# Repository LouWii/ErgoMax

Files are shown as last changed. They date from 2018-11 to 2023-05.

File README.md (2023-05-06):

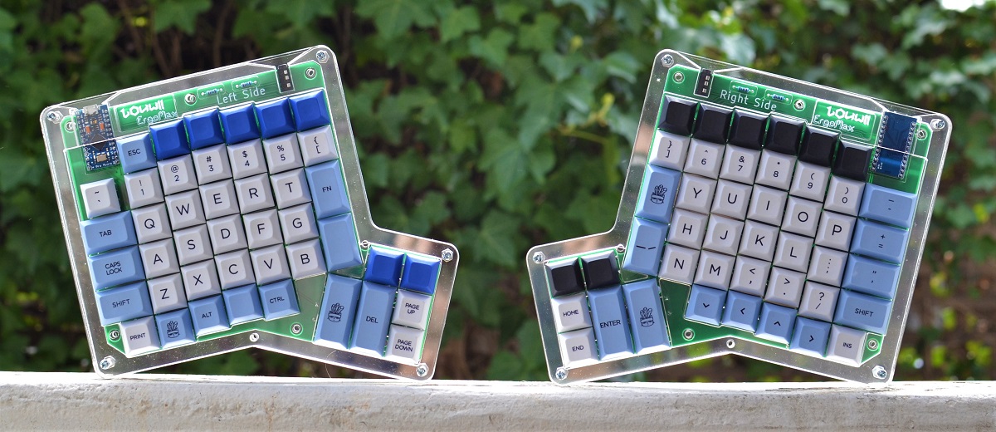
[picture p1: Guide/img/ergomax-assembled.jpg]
Ergomax Keyboard


# ErgoMax

The ErgoMax is a split ergonomic keyboard.

It is based on the ErgoDox, a popular split ergonomic keyboard ([learn more](https://www.ergodox.io/)). 

Its main features/differences are:

* extra top row for F1-F12 keys
* hot-swappable switches
* uses 2 ProMicro controllers (one for each side)
* QMK firmware
* 2 versions of the PCBs:
    * a reversible left+right combined
    * 2 separate PCBs, one for each side
* either side can be master/slave
* both sides can be master (both sides need to be connected via USB in that case), allow for a 1 side only setup
* 2 input pins left (perfect for a rotary encoder!)
* **DIY friendly**: it's really super easy to assemble yourself. The hardest part is probably the ProMicro. But it's still very accessible for beginners.
* multi layer acrylic case

## Layout

While a lot of mechanical keyboard users seem to prefer simplistic, minimal keyboards, the ErgoMax goes the opposite way.

The layout is the same as the ErgoDox, **with an extra top row** for *F1* to *F12* keys, adding more room for activities.

Here's an example:

ergomax-default -layout

## Hotswap - change switches whenever you want

The keyboard PCB has been designed to use **Kailh MX hotswap sockets**. You won't be able to solder the switches directly on the PCBs, you **must** use Kaihl MX sockets.

Switches will plug into the sockets, meaning no solder required for them, and most importantly, meaning that you can remove them and change them easily (hence the *hotswap*...).

## Controller

Each side of the keyboard is controlled via a ProMicro, which is a cheap, small Arduino compatible board running on an ATmega32u4.

The 2 sides can be connected via a 3.5mm jack, just like the original ErgoDox. However, as the 2 sides possess their own ProMicro, that means they can also be working totally independently if needed.

There are 2 pins free on each of the ProMicros, which can be used for whatever you want. I believe it would be possible to drive a RGB strip from it, since it requires only 1 drive pin (you would need to get GND and +5V from somewhere on the PCB). I was able to use both pins to add a rotary encoder.

### Jack connector

I tried to use the same 3.5mm TRRS jack socket as the original ErgoDox, which is a *CP-43514*. But it's not super common, so I changed it for a *PJ320A* (same as *MJ-4PP-9*).

### Firmware

Check the [guides](Guide/README.md)

## Third Party Libraries

We are using several libraries in this project.

* keyboard_parts.pretty [https://github.com/colemarkham/keyboard_parts.pretty](https://github.com/colemarkham/keyboard_parts.pretty) - The Kailh hotswap socket footprint is taken from this project, and has been slightly modified. The 2U stabilizer footprint is from this library as well.
* ProMicroKiCad [https://github.com/Biacco42/ProMicroKiCad](https://github.com/Biacco42/ProMicroKiCad) - The schema and footprint for the ProMicro
* Keebio-Parts.pretty [https://github.com/keebio/Keebio-Parts.pretty](https://github.com/keebio/Keebio-Parts.pretty) - Footprints for the diodes, the PJ320A jack connector, and resistors

### 3D models

Kicad can generate nice 3D previews of PCBs and their components.

As we're using components that are not included in KiCad 3d templates, you'll need to add the next models into your KiCad template folder. On Windows, it's `C:\Users\YOURNAME\kicad\template`, on OSX it's `/Users/YOURNAME/kicad/template`. If the folder doesn't exist, create it.

The 3D models of the hotswap sockets can be found there: [https://github.com/qmk/qmk_hardware](https://github.com/qmk/qmk_hardware). Copy `kailh_socket_mx.stp` into your KiCad template folder.

I couldn't find a 3D model for the PJ320A jack connector. The closest I found is this [https://www.cui.com/product/resource/3dmodel/sj2-3574a-smt-tr](https://www.cui.com/product/resource/3dmodel/sj2-3574a-smt-tr), which gives a good preview of a real PJ320A. Copy `CUI_SJ2-3574A-SMT-TR.step` into your KiCad template folder.

I modified this MX Switch 3D model [https://grabcad.com/library/cherry-mx-switches-mx-1](https://grabcad.com/library/cherry-mx-switches-mx-1) and included it in the `libs/3dmodels` folder of the project as `MX-clean-ergomax.step`. 

I also modified a 2U stabilizer model that I found there [https://grabcad.com/library/cherry-mx-stabilizer-mx-1](https://grabcad.com/library/cherry-mx-stabilizer-mx-1). The file is also included in the `libs/3dmodels` folder of the project as `Stabilizer-closed-ergomax.step`.

I once again modified a ProMicro 3D model [https://grabcad.com/library/arduino-pro-micro-1](https://grabcad.com/library/arduino-pro-micro-1). The file is called `Pro-micro-clean-ergomax.step` and is stored in `libs/3dmodels`.

## Print the PCBs

Here are some manufacturers that can print PCBs for you. They are not in any particular order and I don't have any partnership of any sort either.

* [https://pcbshopper.com/ - price comparison](https://pcbshopper.com/) 
* [https://jlcpcb.com/](https://jlcpcb.com/)
* [https://www.pcbway.com/](https://www.pcbway.com/)
* [https://oshpark.com/](https://oshpark.com/)
* [https://www.pcbcart.com/](https://www.pcbcart.com/)
* [https://www.7pcb.ca/](https://www.7pcb.ca/pcb-fabrication/)
* [https://www.4pcb.com/](https://www.4pcb.com/)
* [https://www.pcbgogo.com/](https://www.pcbgogo.com/)
* [https://dirtypcbs.com/](https://dirtypcbs.com/)

## Assembly

Check the [guides](Guide/README.md)

## Case

[See Case readme](./Case/)

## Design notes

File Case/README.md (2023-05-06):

## Case

### Acrylic

A case composed of different laser-cut acrylic layers.

[More](./Acrylic/)

### Solid bottom

A solid 3d bottom case, potentially usable for 3d printing or CNC machining.

[More](./Solid%20Bottom%20Case/)

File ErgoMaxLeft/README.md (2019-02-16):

# ErgoMax - Left side

This is the left side, for the left hand.

## PCB

Render from Kicad (light source in Kicad isn't changeable...)

ergomax-left-pcb-4-front

ergomax-left-pcb-4-back

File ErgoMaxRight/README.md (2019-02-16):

# ErgoMax - Right side

This is the right side, for the right hand.

## PCB

Render from Kicad (light source in Kicad isn't changeable...)

ergomax-right-pcb-4-front

ergomax-right-pcb-4-back

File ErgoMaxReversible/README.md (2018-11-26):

# ErgoMax Reversible

As its name suggests, the reversible PCB can be used for either the left side or right side. 

## PCB

Render from KiCad.

ergomax-reversible-rightside

ergomax-reversible-leftside

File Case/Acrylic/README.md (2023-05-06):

## Case - Acrylic

A case composed of different laser-cut acrylic layers.

The design is dependant on using different thicknesses for the layers. The thickness availability depends on where you get the acrylic laser cut, hence why the designs might need to be adjusted if you can't source the correct thickness.

### MakerLabs

[More](./MakersLabs/)

### Ponoko

[More](./Ponoko/)

### Work files

[More](./WIP/)

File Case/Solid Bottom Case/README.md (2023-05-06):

## Case - Solid Bottom

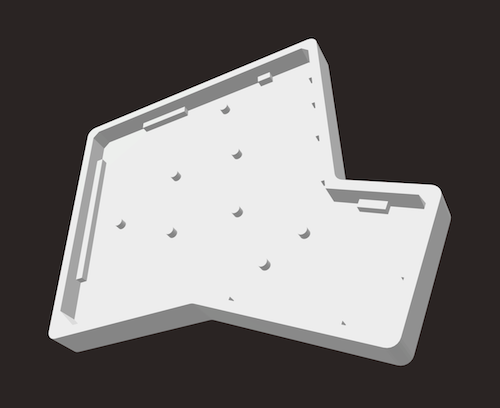
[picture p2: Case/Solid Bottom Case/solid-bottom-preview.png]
Ergomax bottom case 3d preview


A solid bottom case, potentially usable for 3d printing or CNC machining.

I never went further with the idea. I can't say for sure if the 3d models are good for any usage.

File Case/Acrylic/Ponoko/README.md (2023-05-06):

## Acrylic Case - Ponoko

This was an attempt at producing the files to get them laser cut with Ponoko.

I never pursued that idea, I can't confirm those files work. Technically, they should.

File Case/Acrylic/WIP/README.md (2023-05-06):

## Acrylic Case - Work files

The files in this folder were used during the designing process of the acrylic case.

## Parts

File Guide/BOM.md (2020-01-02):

# BOM (list of components)

This is for **one side**. If you're making 2 sides, double that up.

* 1x ProMicro board (and 2 2.52mm pin headers)
* 2x 2.2kohm resistors
* 1x PJ-320A or MJ-4PP-9 3.5mm jack connector
* 44x Kailh MX sockets
* 44x 1N4148 diodes (**through hole**)
* 44x MX Cherry (or MX compatible) keyboard switches
* 2x 2U stabilizers (optional)

### About diodes

Given the important number of diodes types/models out there, I made some research on what's a good diode/bad diode for a keyboard, because I had no idea (yay, learning!). Turns out it's not that easy to understand without a good knowledge in electronics. But at the same time, keyboards don't require a really specific diode, just one that has a switching time that's short enough(?). So in the end, the easiest solution is to use a 1N4148, which is one of the most common diodes, is cheap, and apparently is a good fit for a keyboard.

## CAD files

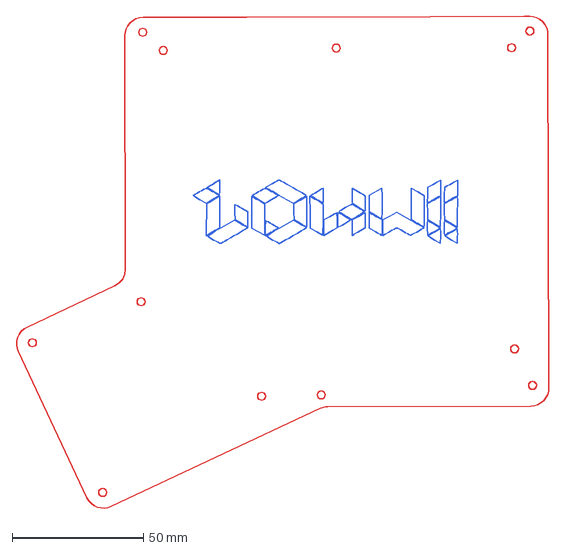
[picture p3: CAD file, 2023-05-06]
Case/Acrylic/MakersLabs/Layer 5 - right.dxf
202.9 x 188.2 mm

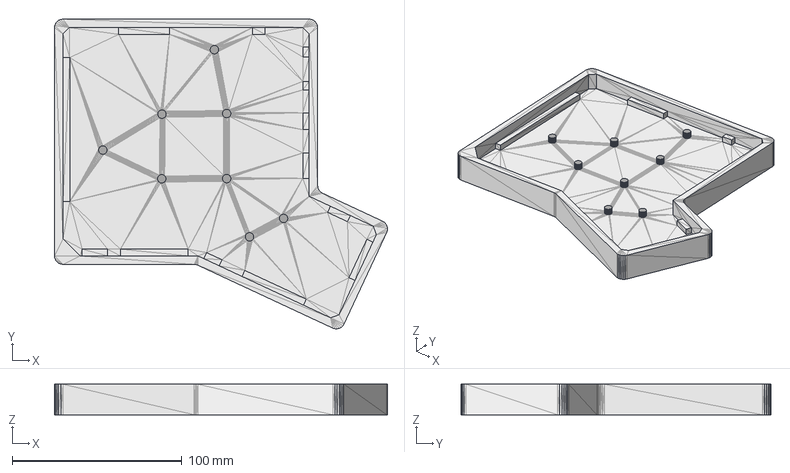
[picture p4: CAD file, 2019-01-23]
Case/Solid Bottom Case/ErgoMax-Left-Case.step
196.5 x 182.8 x 18.0 mm

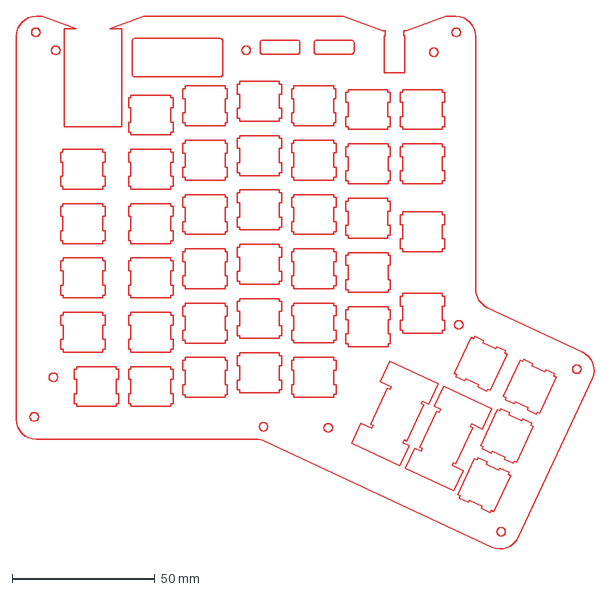
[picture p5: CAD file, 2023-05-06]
Case/Acrylic/MakersLabs/Layer 3.dxf
202.8 x 187.7 mm

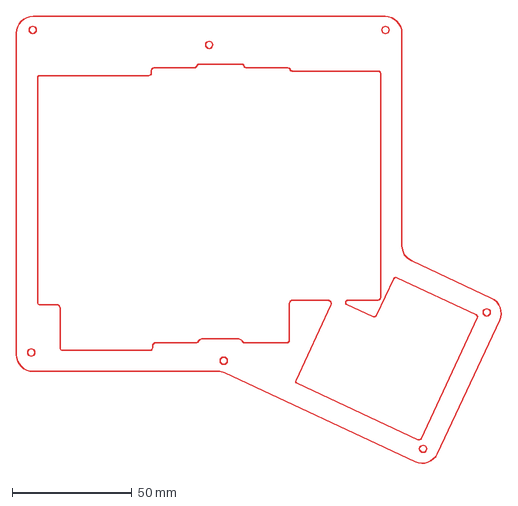
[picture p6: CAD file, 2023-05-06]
Case/Acrylic/MakersLabs/Layer 1.dxf
202.8 x 187.7 mm

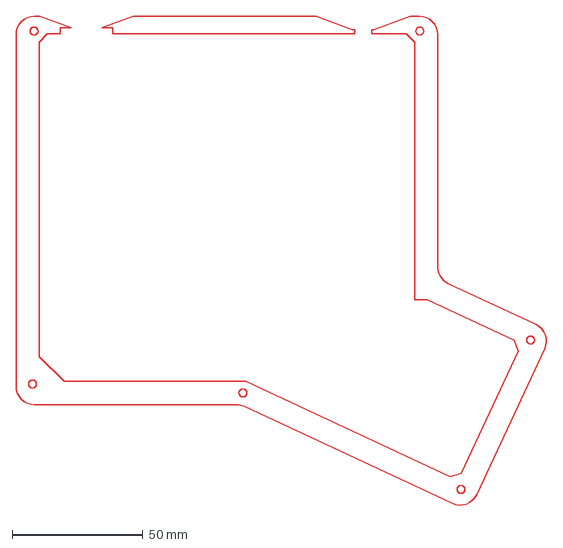
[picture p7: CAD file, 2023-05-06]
Case/Acrylic/MakersLabs/Layer 4.dxf
202.8 x 187.7 mm

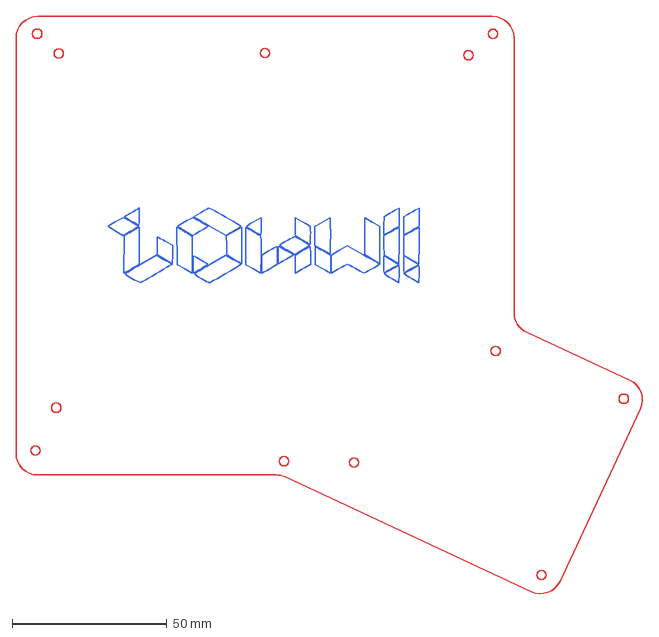
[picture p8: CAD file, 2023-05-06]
Case/Acrylic/MakersLabs/Layer 5 - left.dxf
202.8 x 187.7 mm

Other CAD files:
CAD/Acrylic/left - plate.dwg
Case/Acrylic/Ponoko/ponoko - layer 1 3 5.dwg
Case/Acrylic/WIP/Layer all.dwg
Case/left - PCB silk.dwg
Case/Acrylic/Ponoko/ponoko - layer 2 no extra.dwg
Case/Acrylic/WIP/left - layer 3 - plate.dwg
Case/Solid Bottom Case/ErgoMax-Left.stl
Case/Acrylic/Ponoko/ponoko - layer 2 doubled no extra.dwg
Case/Acrylic/WIP/left - layer 1.dwg
Case/Acrylic/Ponoko/ponoko - layer 4 with extra.dwg
Case/Acrylic/WIP/left - bottom.dwg
Case/Acrylic/Ponoko/ponoko - layer 1 3 5 no extra.dwg
Case/Acrylic/MakersLabs/Layer 2.dxf
Case/Acrylic/Ponoko/ponoko - layer 4 doubled no extra.dwg
Case/Acrylic/Ponoko/ponoko - layer 4 no extra.dwg
Case/Acrylic/WIP/left - layer 2.dwg
Case/Acrylic/WIP/left - layer 4.dwg
Case/Solid Bottom Case/ErgoMax-Left.dwg

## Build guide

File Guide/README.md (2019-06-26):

# Guides

* [Assembly](ASSEMBLY.md)
* [Firmware](FIRMWARE.md)

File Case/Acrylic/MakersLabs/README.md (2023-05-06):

## Acrylic Case - MakerLabs

Ergomax acrylic case laser cut

This is the version of the case that I got laser cut at a local shop called MakerLabs. It's the only one I have, and used for a while on my ErgoMax. It's using different thicknesses of acrylic sheets.

* Layer 1: 3mm (top)
* Layer 2: 4.5mm
* Layer 3: 3mm
* Layer 4: 6mm
* Layer 5: 3mm (bottom)

Each file works for any side, except the layer 5 that has a logo on it which is why there's a separate left and right.

The idea was to get the logo etched on the bottom layer, but it apaprently had issues and I was not able to get that done.

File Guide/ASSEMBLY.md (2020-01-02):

# Assembly

Here comes the fun part!

## Parts list

Make sure you have everything, check the [BOM](BOM.md)

## Process

First, make sure you understand on which side of the PCB you're supposed to solder/place the component on. This is easy for the left/right PCBs, a bit harder for the reversible PCB version.

The top of the PCB is where the switches will be on. On that side, we'll also have the ProMicro, 3.5mm jack connector, the 2 resistors and the 2 stabilizers.

On the bottom of the PCB, we'll have the 44 Kailh sockets and the 44 diodes.

**Note:** The 2 resistors can probably be soldered on the back, if you want to.

To give you an idea, here are the assembled PCBs.

### Left Side

#### Front

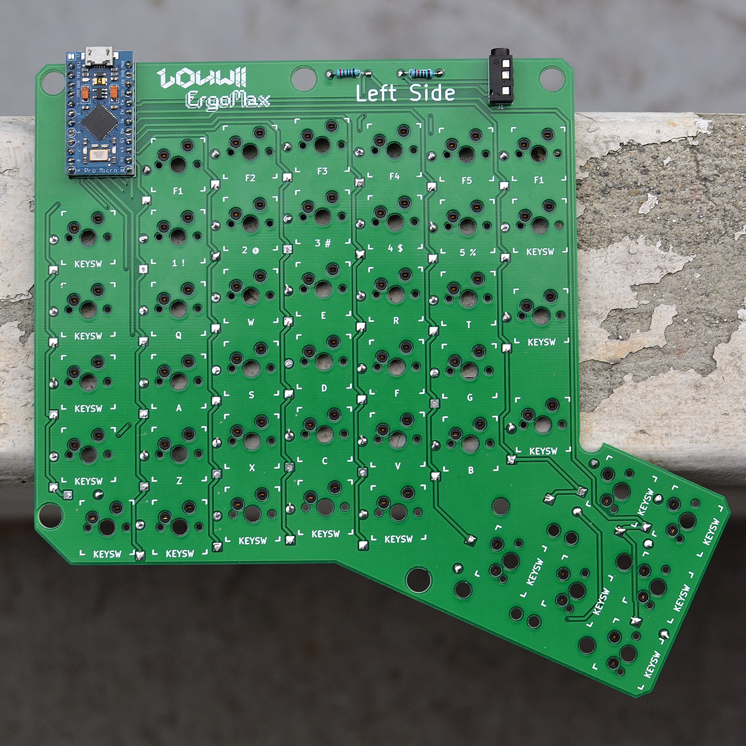
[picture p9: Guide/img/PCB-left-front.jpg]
Left PCB - front


#### Back

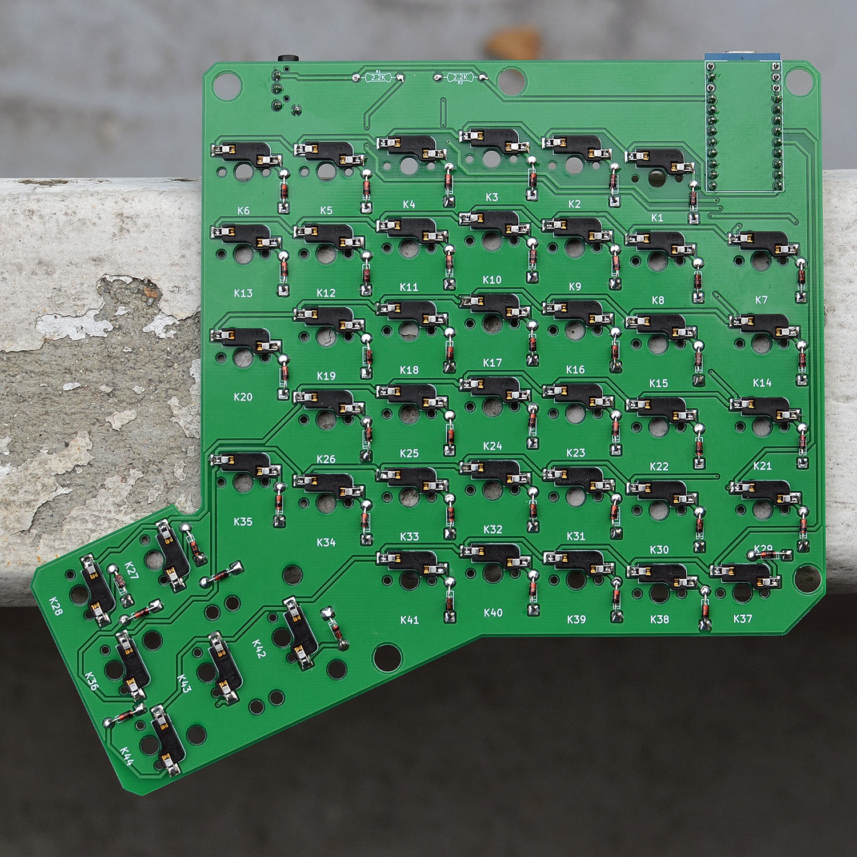
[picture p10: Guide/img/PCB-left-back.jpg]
Left PCB - back


### Right Side

#### Front

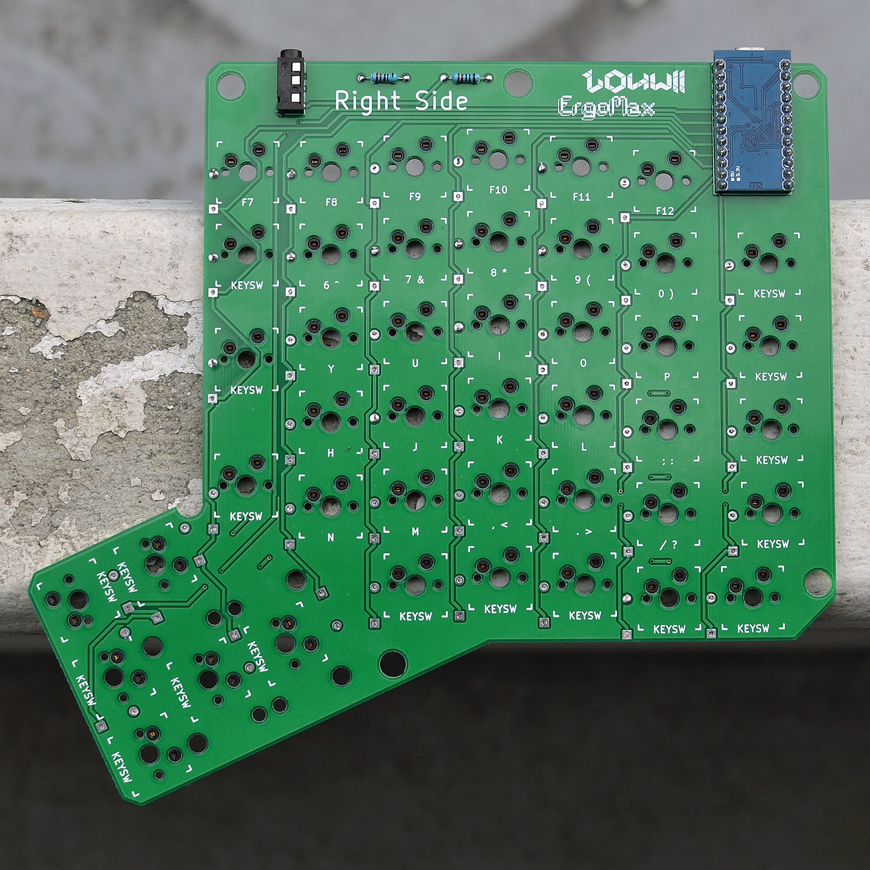
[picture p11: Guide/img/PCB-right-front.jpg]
Right PCB - front


#### Back

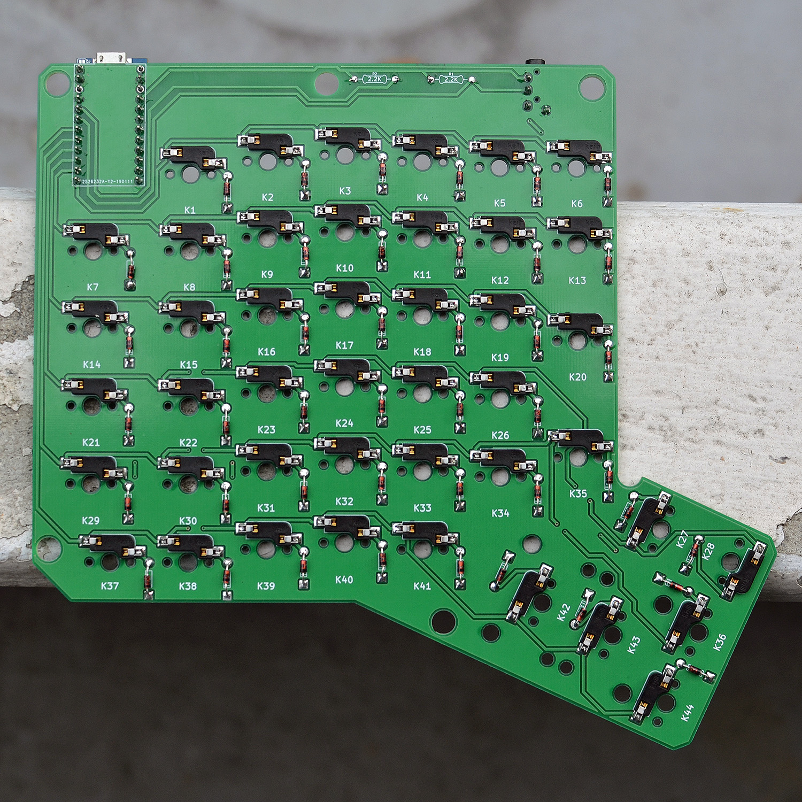
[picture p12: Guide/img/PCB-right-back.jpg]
Right PCB - back


### Step by step

#### Inserting Kailh sockets

The sockets fit very tightly on the PCB, maybe a bit too tight as they can be hard to put them in place. The good news is: this will prevent them from getting pulled off of the PCB when inserting a switch.

I recommend using a flat piece of wood to evenly put pressure on the socket until it sits flush with the PCB. You might need to put some good force on it. Make sure the socket is really flush with the PCB, otherwise it'll be harder to solder the socket later on.

I know, this isn't really fun. But take your time, don't rush, you might end up with a broken socket or worse.

#### Soldering the diodes

#### Soldering the resistors

#### Soldering the jack connector

#### Testing the ProMicro

Before soldering the ProMicro on the PCB, I advise you to test it. If, for some reason, the ProMicro doesn't work, it'll be a pain to remove.

Get a micro-USB cable, and flash a firmware on it.

#### Soldering the ProMicro

We're almost there! The hardest part left, the ProMicro.

The goal is not to mess it up and not bridge 2 pins. Take your time, do this in a well lit place (use your phone as a flashlight if needed). The pins and holes/pads are small and don't require a lot of solder. Heat up the pad an pin and place a small amount of solder. If you're having issues, a bit of flux might help.

Once done, make sure your solders are clean and that there are no bridges at all (2 pins or pads touching because you put too much solder on).

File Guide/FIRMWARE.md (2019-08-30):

# Firmware

Ergomax's firmware is based on [QMK](https://qmk.fm/), the (most?) popular firmware for custom keyboards.

The firmware is hosted on a separate repository (fork of QMK) in the *ergomax-keyboard* branch: [LouWii/qmk_firmware](https://github.com/LouWii/qmk_firmware)

To read more, go to the Ergomax folder [qmk/keyboards/ergomax](https://github.com/LouWii/qmk_firmware/tree/ergomax-keyboard/keyboards/ergomax)

### Keyboard Firmware Builder

[kbfirmware.com](https://kbfirmware.com/) is a nice tool that makes it easy to create a firmware based on QMK. You just have to setup your layout, enter the settings, enter the layout and layers, enter macros and even custom code, and then the tool compiles a firmware for you, or you can even download the source files if you want to.

I've created a file for the left side and right side so you don't have to setup everything in the tool. Just upload `ErgoMaxLeft/kfb-layout.json` or  `ErgoMaxRight/kfb-layout.json` and add your own customizations.

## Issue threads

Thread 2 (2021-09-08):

Case Information

leifniem, 2021-09-08:
A friend of mine wants my help building this board and i'm a little lost on the case part of the keyboard.

The included STEP / STL file would be suitable for 3D printing if i'm not mistaken, but it seems to be lacking the cutouts for the connectors, if i assume correctly.

On the acrlyic version i fail to understand if multiple middle layers are needed to acommodate the distance between switches and PCB, or alternatively a thicker middle part.

Sorry to bug if those are things that should be self-explanatory.

Thanks :)

LouWii, 2021-09-18:
Hi,

I'll be completely honest, I'm a complete noob in regards to 3d modelling. And I don't remember entirely what I produced for this board. The step/stl is probably un-complete, since I didn't go for 3d printing. I used it more as a preview to see how it would look.

The acrylic version should work though, since that's the route I went for. But again, I don't remember entirely what I did there 🤦‍♂️ The workshop I went to didn't have a large choice of thicknesses, so I had to accommodate for that in my design.

leifniem, 2021-09-18:
No worries, my friend just ordered all the parts so it's not remotely too late :)

But good to know my assumption about the 3D thing was right. With the vector files of the acrylic I should be able to whip up a printable case I think, I'll let you know in case we try that.

Thanks a lot and I hope you had a great vacation :)

LouWii, 2021-09-18:
Good luck! I'd love to see a few pics once it's all built

leifniem, 2022-02-17:
> Do you know how thick the acrylic needs to be to cut it?

We went for a 3D printed case, so I sadly do not

jaspreetlall, 2023-05-02:
@leifniem Any chance you could share the 3D printable case files? Would really appreciate if you could.

Thank you.

leifniem, 2023-05-02:
> @leifniem Any chance you could share the 3D printable case files? Would really appreciate if you could.
>
> Thank you.

Never got around to fixing them. How fit are you with CAD?

jaspreetlall, 2023-05-02:
No worries. I thought of asking since you mentioned choosing to go with printing. Thank you for your reply though.

And I barely ever used CAD but have someone I know who can tinker a little bit. They'd be able to tweak things but not design per se. What kind of fixes might be needed? I can definitely ask them.

leifniem, 2023-05-02:
> No worries. I thought of asking since you mentioned choosing to go with printing. Thank you for your reply though.
>
> And I barely ever used CAD but have someone I know who can tinker a little bit. They'd be able to tweak things but not design per se. What kind of fixes might be needed? I can definitely ask them.

My friend who had to file the case to measure is currently on vacation, so I cannot give you the exact modifications he had to make, but  think it was standoffs and cutouts for the USB ports and bridge cable. I'll see if I can find pictures of it.

jaspreetlall, 2023-05-02:
Thank you, pictures would be helpful to plan in the mean time.
It's okay too if you aren't able to find those, can wait for your friend to be back from vacation 🙂.
Thank you once again.

Closed 2021-09-18.

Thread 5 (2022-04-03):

[question] Does the PCB work with Kailh Low Profile Choc Switches?

alain-sarti, 2022-04-03:
Hi there,

I am new to the whole mechanical keyboard topic so maybe this question is a bit stupid, but I wanted to ask if the PCB is compatible with Kailh Low Profile Choc Switches? I want to use those and find the extra F-keys on this layout intriguing.

Thanks in advance

LouWii, 2022-04-04:
I actually don't know. You will have to check if they have the same footprint as regular Cherry MX switches. What I'm sure though is that the case I designed will not work with those switches.

alain-sarti, 2022-04-04:
Thanks for the information, I'll check and if it does I'll let you know ☺️

madushan1000, 2023-07-11:
@alain-sarti did you ever find out if they're compatible?

alain-sarti, 2023-07-11:
I don't know for sure, but mx and choc are not compatible according to this webpage: https://learn.adafruit.com/neokey-breakout/overview

Closed 2022-04-04.

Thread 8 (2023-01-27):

Soldering Tips - Reversible PCB

jaspreetlall, 2023-01-27:
Has anyone built the keyboard using reversible PCB?
Would be great if you can share some helpful tips.

To keep the pricing low and nobody to share the cost of PCB printing, I decided to go this route of printing reversible boards. Only after the prints were delivered, l found out that the component markings are only visible on one side.

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

By now you'd already know my level of skills with electronics, lol. I want to do my best efforts in 1st attempt as redoing would be a whole new level of complexity for me.

Any help or tips are welcome.

Side note - I am located in Vancouver, BC region and have spare prints in case interested in building this KB. We can split the cost, saves you printing and shipping time.

Thank you.

LouWii, 2023-02-02:
Hey,

I haven't got the reversible PCBs built, so I can't really help right now. I made it as an experiment, but it might work. I'm willing to buy a PCB set off you and have a go at it if you want. I can even come pick it up in person.

jaspreetlall, 2023-02-14:
Oh thank you very much @LouWii!
Somehow I missed the notification here. I started right side for now following the images of completed builds, haven't completed yet though.

I'll get in touch with you via email and plan something.

BenMMcLean, 2023-02-16:
You will need to solder a wire between the ground pin of the microcontroller (on the left hand board, that is the second from the top right) and the ground pin of the TRRS jack (it is the pin apart from the column of three) if you want the boards to work together over a TRRS cable.

jaspreetlall, 2023-05-01:
@BenMMcLean thank you for the tip. Definitely helpful. Will do it towards the end of the build.

Namgugn, 2023-05-15:
Can you share how the build went? I also ordered a Reversible PCB, and I wonder if it is possible to build with this.

sohocoke, 2023-05-17:
I just finished a build of the reversible PCB and can confirm the reversible PCB works fine with a TRRS cable.

There's nothing too tricky – just pay attention to which side of the board you need to solder the components to, as shown in the photos. There's no need for a wire anymore.

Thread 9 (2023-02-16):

Ground plane is disconnected on reversible PCB

BenMMcLean, 2023-02-16:
First off, great project! This board is exactly what I was looking for.

On the reversible PCB, the ground plane is not connected to the microcontroller. This condition allows each half to operate individually but they cannot operate together over a TRRS cable, as the microcontrollers will not share a ground. This could be fixed by adding a ground plane on both sides of the PCB.

Having assembled the board, everything else appears to function correctly (although it would be nice to have a 5 pin switch footprint).

LouWii, 2023-02-17:
Thanks for the feedback @BenMMcLean. Could you post some pictures? I'm curious about how it looks, I've never built the reversible PCB version.

I actually don't know why I haven't used the 5 pins switch footprint. I need to motivate myself to change that and fix the ground plane.

BenMMcLean, 2023-02-17:
Yeah sure! I haven't got a photo of the wire I spliced between the Microcontroller & TRRS jack, but I've attached a picture of the completed board & the bare PCB.

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

I had to make some modifications to the acrylic case in order to fit my microcontroller and the TRRS jack, but it otherwise fit pretty well.

LouWii, 2023-02-18:
Nice, it looks pretty good with a white case. Do you mind if I add the pictures somewhere in one of the doc?

BenMMcLean, 2023-02-18:
Go ahead!

MLouttit, 2023-02-18:
Thanks for the heads up @BenMMcLean! I ordered PCBs before the change, so I'll get a photo of the wire if I remember. Out of interest, what keycap set is that?

BenMMcLean, 2023-02-19:
@MLouttit It's a combination of a few sets actually. I found it cheaper to buy a specific "ergodox" set rather than parting out individual 1.5 and 2u keys, so I got the green keycaps from [here](https://www.aliexpress.com/item/1005004040895139.html?spm=a2g0o.order_list.order_list_main.325.58cb1802QDpweG). The pink caps I had left over from a different build, bought from here [here](https://www.aliexpress.com/item/1005004021955113.html?spm=a2g0o.order_list.order_list_main.320.58cb1802QDpweG). The rest of the keys are just a generic set for a standard keyboard, I paid about AUD$20 for them.

BenMMcLean, 2023-05-06:
> Hi, I am waiting for my reversible PCBs to arrive. Is this issue rectifiable after the board has been printed?

If you downloaded the gerbers after February 17, you have a revised version of the board without this issue. If your gerbers are from a date prior, the fix is extremely simple. All you need to do is splice a wire between the ground on the TRRS jack and the ProMicro. I've highlighted the two pins you need to connect in the diagram below (make sure you've got the board the same way up I do):
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

Closed 2023-05-06.

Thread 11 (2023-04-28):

Question: switch plate needed?

sohocoke, 2023-04-28:
Hi, I love this layout and am planning to order parts and give it a shot. I'm considering it a prototyping effort to find zero-in on the right switch and layout, so am planning to do a minimal build without a case.

One question: do the MX switches stay secure enough in the socket for daily use without a switch plate securing them? The Gerber file doesn't have an FR4 switch plate so hoping this is the case.

jaspreetlall, 2023-05-01:
No, not stable at all.
I am in the process of building this board as well.
Tried installing switches without the plate (I don't have it made yet) and I'd say that it won't be usable in any real life scenario. The pins on the switches are delicate and the middle stem is just minimal support.

All that being said, this is the first time I am ever building a keyboard so I am using all the parts for the first time. I am willing to share some pictures if you need.

LouWii, 2023-05-02:
@jaspreetlall are you using 3 pins or 5 pins switches?

I've tested out with 5 pins Gateron blacks and they fit quite snug on the PCB, I think it would be fine to use them like that. 3 pins switches are too loose for sure.

@sohocoke You could try to use one of the CAD files to make a plate. Layer 3 is the one that would be the plate. I'm not sure if having just a plate without the entire case would help that much, but I've never tried.

sohocoke, 2023-05-02:
@jaspreetlall @LouWii Thanks for your help. I ordered Kailh Speed Coppers which I've just found are 3-pin switches. 😟

I'll have a look at the CAD files and see if I could make a plate, but since this is my first build attempt I guess even if I pull it off, it might take me quite some time.

LouWii, 2023-05-04:
Yeah the reversible PCB doesn't support 5 pins switches. I don't remember why I made it that way :/

BenMMcLean, 2023-05-06:
@LouWii

I am working on a 5-pin revision. Haven't made a PR yet since the routing is pretty bad and I haven't validated it yet, but if you want you can see it in the main branch of my fork -> https://github.com/BenMMcLean/ErgoMax

sohocoke, 2023-05-06:
`CAD/Acryllic/left - layer 3 - plate.pdf` seems to have some content truncated.

I found a way to convert the .dwg file to a .dxf file that I could open in LibreCAD. There are a few layers in this file. The layer for the switch plate seems to be 'Orig switch cut' – could you confirm?

My plan is to get quotes from a local acrylic laser cutting service and order if the price is reasonable.

LouWii, 2023-05-06:
@sohocoke I've updated the repo and cleaned up the files for the case. Have a look there: https://github.com/LouWii/ErgoMax/tree/master/Case/Acrylic/MakersLabs These are the files I used to build the case for my ErgoMax. Layer 3 is indeed the plate.

sohocoke, 2023-05-17:
I just finished building the reversible version and found out that with the Kailh hot swap sockets and Kailh Speed Silver switches, the switches are relatively secure and don't wobble in normal use at my desk. So no switch plate is necessary, although it would definitely make things more stable if you plan to move the keyboard around a lot.

Closed 2023-05-17.

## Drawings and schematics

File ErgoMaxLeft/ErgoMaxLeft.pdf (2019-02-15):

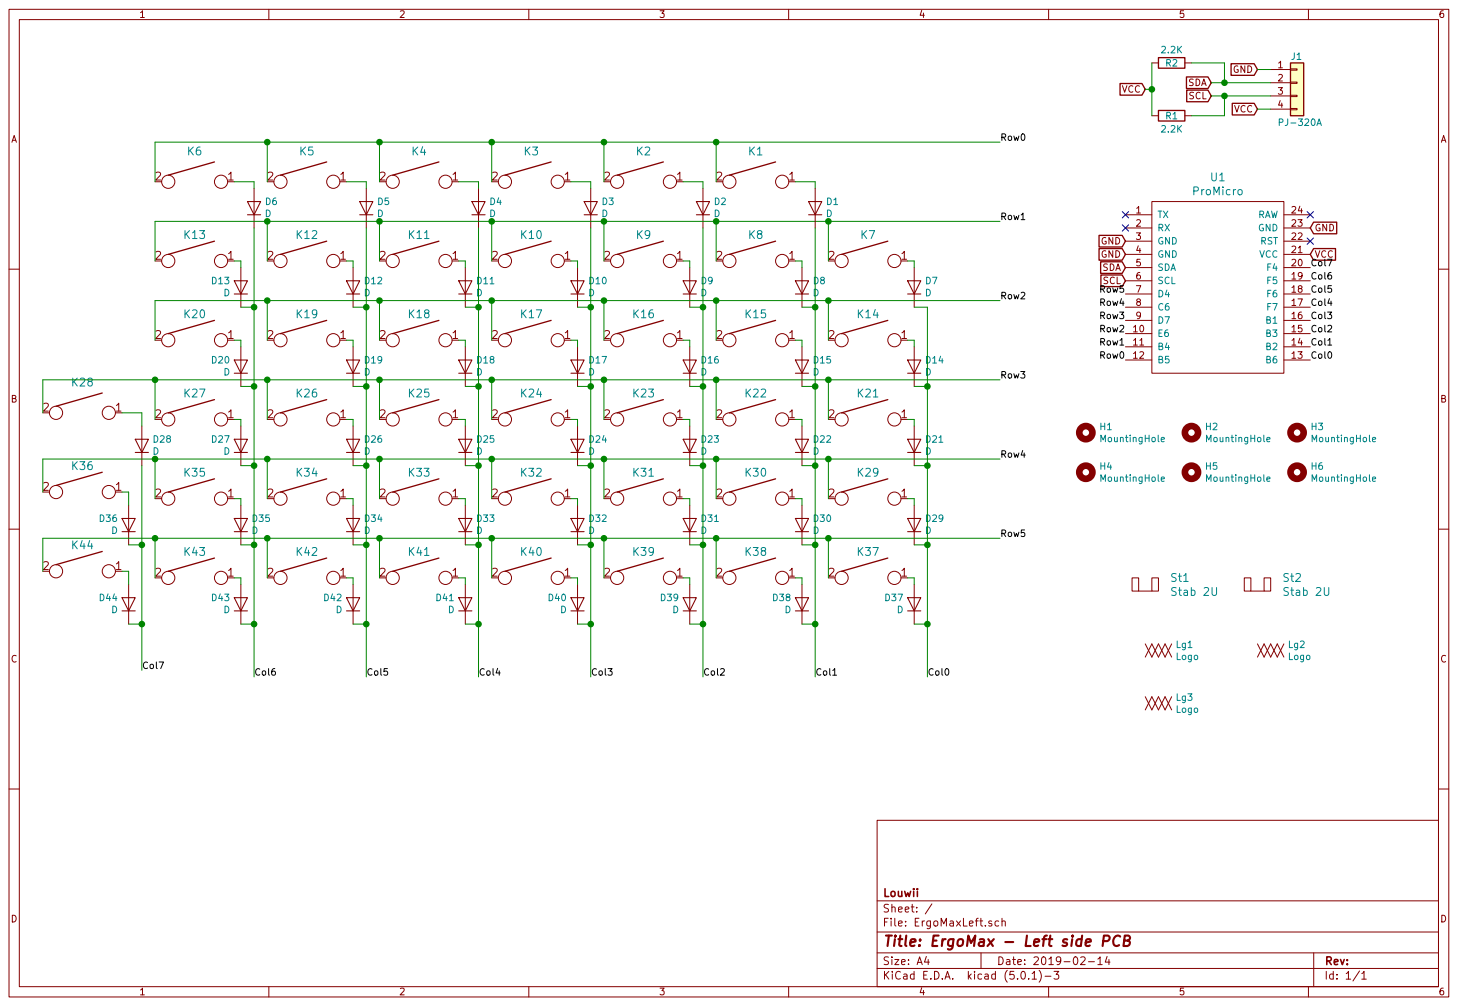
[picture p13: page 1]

File: ErgoMaxLeft.sch Sheet: / Louwii

Id: 1/1 Title: ErgoMax - Left side PCB

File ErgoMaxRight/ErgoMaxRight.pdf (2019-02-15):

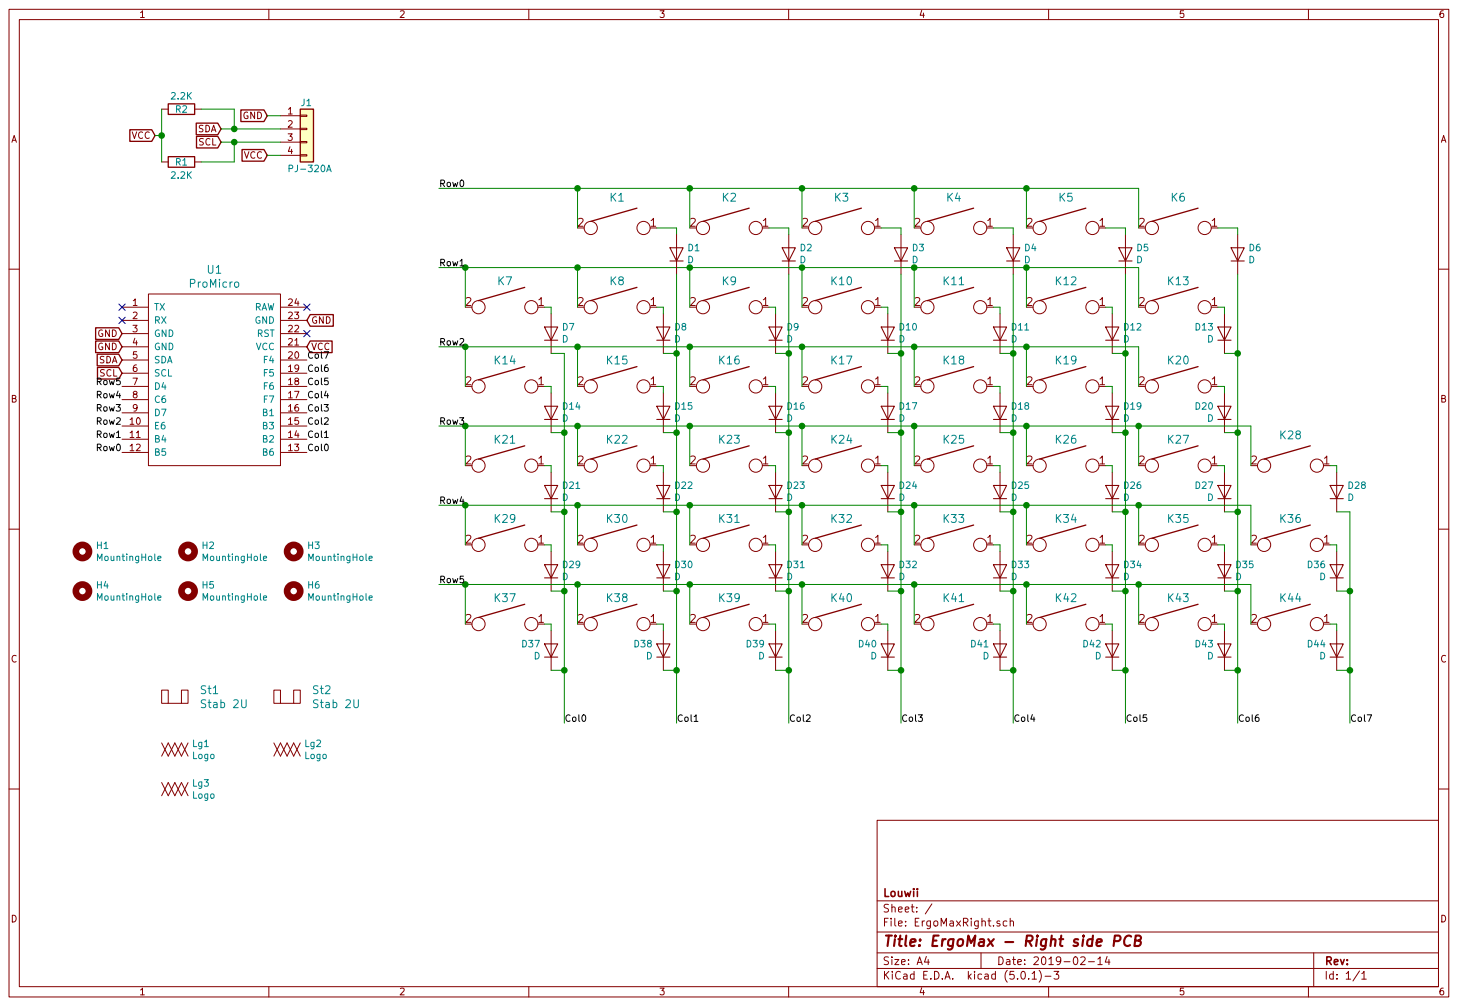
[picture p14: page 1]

File: ErgoMaxRight.sch Sheet: / Louwii

Id: 1/1 Title: ErgoMax - Right side PCB

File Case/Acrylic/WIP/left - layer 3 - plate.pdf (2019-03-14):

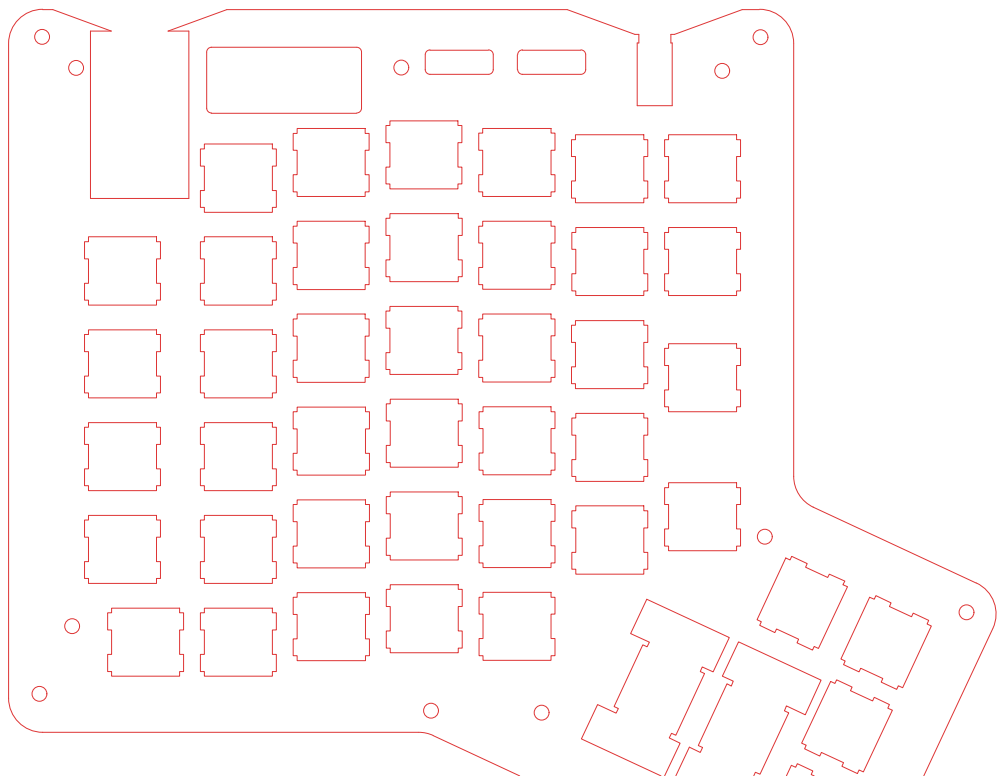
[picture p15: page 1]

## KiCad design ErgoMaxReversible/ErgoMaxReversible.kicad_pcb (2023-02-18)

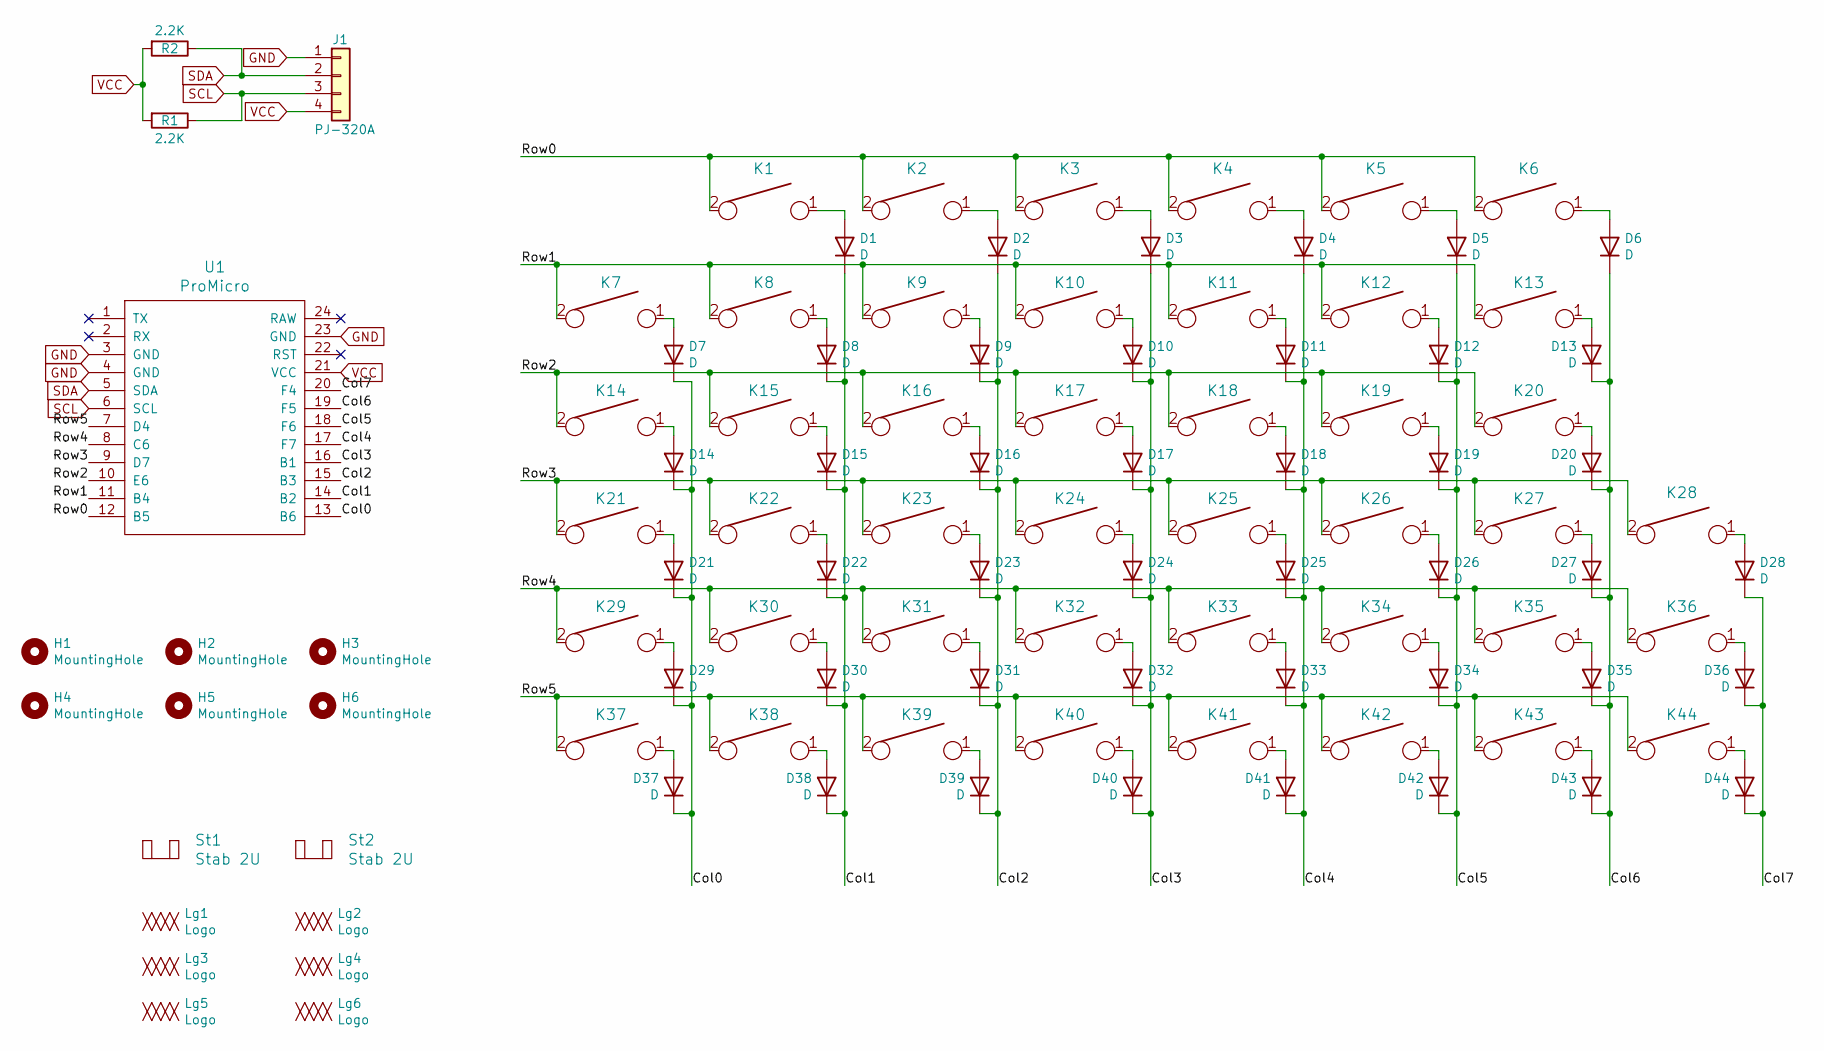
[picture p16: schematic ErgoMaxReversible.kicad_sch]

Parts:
D1, D2, D3, D4, D5, D6, D7, D8, D9, D10, D11, D12, D13, D14, D15, D16, D17, D18, D19, D20, D21, D22, D23, D24, D25, D26, D27, D28, D29, D30, D31, D32, D33, D34, D35, D36, D37, D38, D39, D40, D41, D42, D43, D44: D; Diode_Long_Reversible-No3dModel
H1, H2, H3, H4, H5, H6: MountingHole; MountingHole_6mm
J1: PJ-320A; TRRS-PJ-320A-dual
K1, K2, K3, K4, K5, K6, K7, K8, K9, K10, K11, K12, K13, K14, K15, K16, K17, K18, K19, K20, K21, K22, K23, K24, K25, K26, K27, K28, K29, K30, K31, K32, K33, K34, K35, K36, K37, K38, K39, K40, K41, K42, K43, K44: KEYSW; Kailh_socket_MX_reversible
Lg1, Lg3: Logo; LouWii-logo
Lg2, Lg4: Logo; ErgoMax-logo
Lg5: Logo; LeftSideText
Lg6: Logo; RightSideText
R1, R2: 2.2K; Resistor
St1, St2: Stab 2U; Mx_Stab_200
U1: ProMicro; ProMicroReversible

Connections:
/Col0: D7.1 (K), D14.1 (K), D21.1 (K), D29.1 (K), D37.1 (K), U1.13 (B6)
/Col1: D1.1 (K), D8.1 (K), D15.1 (K), D22.1 (K), D30.1 (K), D38.1 (K), U1.14 (B2)
/Col2: D2.1 (K), D9.1 (K), D16.1 (K), D23.1 (K), D31.1 (K), D39.1 (K), U1.15 (B3)
/Col3: D3.1 (K), D10.1 (K), D17.1 (K), D24.1 (K), D32.1 (K), D40.1 (K), U1.16 (B1)
/Col4: D4.1 (K), D11.1 (K), D18.1 (K), D25.1 (K), D33.1 (K), D41.1 (K), U1.17 (F7)
/Col5: D5.1 (K), D12.1 (K), D19.1 (K), D26.1 (K), D34.1 (K), D42.1 (K), U1.18 (F6)
/Col6: D6.1 (K), D13.1 (K), D20.1 (K), D27.1 (K), D35.1 (K), D43.1 (K), U1.19 (F5)
/Col7: D28.1 (K), D36.1 (K), D44.1 (K), U1.20 (F4)
/Row0: K1.2, K2.2, K3.2, K4.2, K5.2, K6.2, U1.12 (B5)
/Row1: K7.2, K8.2, K9.2, K10.2, K11.2, K12.2, K13.2, U1.11 (B4)
/Row2: K14.2, K15.2, K16.2, K17.2, K18.2, K19.2, K20.2, U1.10 (E6)
/Row3: K21.2, K22.2, K23.2, K24.2, K25.2, K26.2, K27.2, K28.2, U1.9 (D7)
/Row4: K29.2, K30.2, K31.2, K32.2, K33.2, K34.2, K35.2, K36.2, U1.8 (C6)
/Row5: K37.2, K38.2, K39.2, K40.2, K41.2, K42.2, K43.2, K44.2, U1.7 (D4)
GND: J1.1, U1.3 (GND), U1.4 (GND), U1.23 (GND)
unnamed: D1.2 (A), K1.1
unnamed: D2.2 (A), K2.1
unnamed: D3.2 (A), K3.1
unnamed: D4.2 (A), K4.1
unnamed: D5.2 (A), K5.1
unnamed: D6.2 (A), K6.1
unnamed: D7.2 (A), K7.1
unnamed: D8.2 (A), K8.1
unnamed: D9.2 (A), K9.1
unnamed: D10.2 (A), K10.1
unnamed: D11.2 (A), K11.1
unnamed: D12.2 (A), K12.1
unnamed: D13.2 (A), K13.1
unnamed: D14.2 (A), K14.1
unnamed: D15.2 (A), K15.1
unnamed: D16.2 (A), K16.1
unnamed: D17.2 (A), K17.1
unnamed: D18.2 (A), K18.1
unnamed: D19.2 (A), K19.1
unnamed: D20.2 (A), K20.1
unnamed: D21.2 (A), K21.1
unnamed: D22.2 (A), K22.1
unnamed: D23.2 (A), K23.1
unnamed: D24.2 (A), K24.1
unnamed: D25.2 (A), K25.1
unnamed: D26.2 (A), K26.1
unnamed: D27.2 (A), K27.1
unnamed: D28.2 (A), K28.1
unnamed: D29.2 (A), K29.1
unnamed: D30.2 (A), K30.1
unnamed: D31.2 (A), K31.1
unnamed: D32.2 (A), K32.1
unnamed: D33.2 (A), K33.1
unnamed: D34.2 (A), K34.1
unnamed: D35.2 (A), K35.1
unnamed: D36.2 (A), K36.1
unnamed: D37.2 (A), K37.1
unnamed: D38.2 (A), K38.1
unnamed: D39.2 (A), K39.1
unnamed: D40.2 (A), K40.1
unnamed: D41.2 (A), K41.1
unnamed: D42.2 (A), K42.1
unnamed: D43.2 (A), K43.1
unnamed: D44.2 (A), K44.1
SCL: J1.3, R1.1, U1.6 (SCL)
SDA: J1.2, R2.1, U1.5 (SDA)
VCC: J1.4, R1.2, R2.2, U1.21 (VCC)

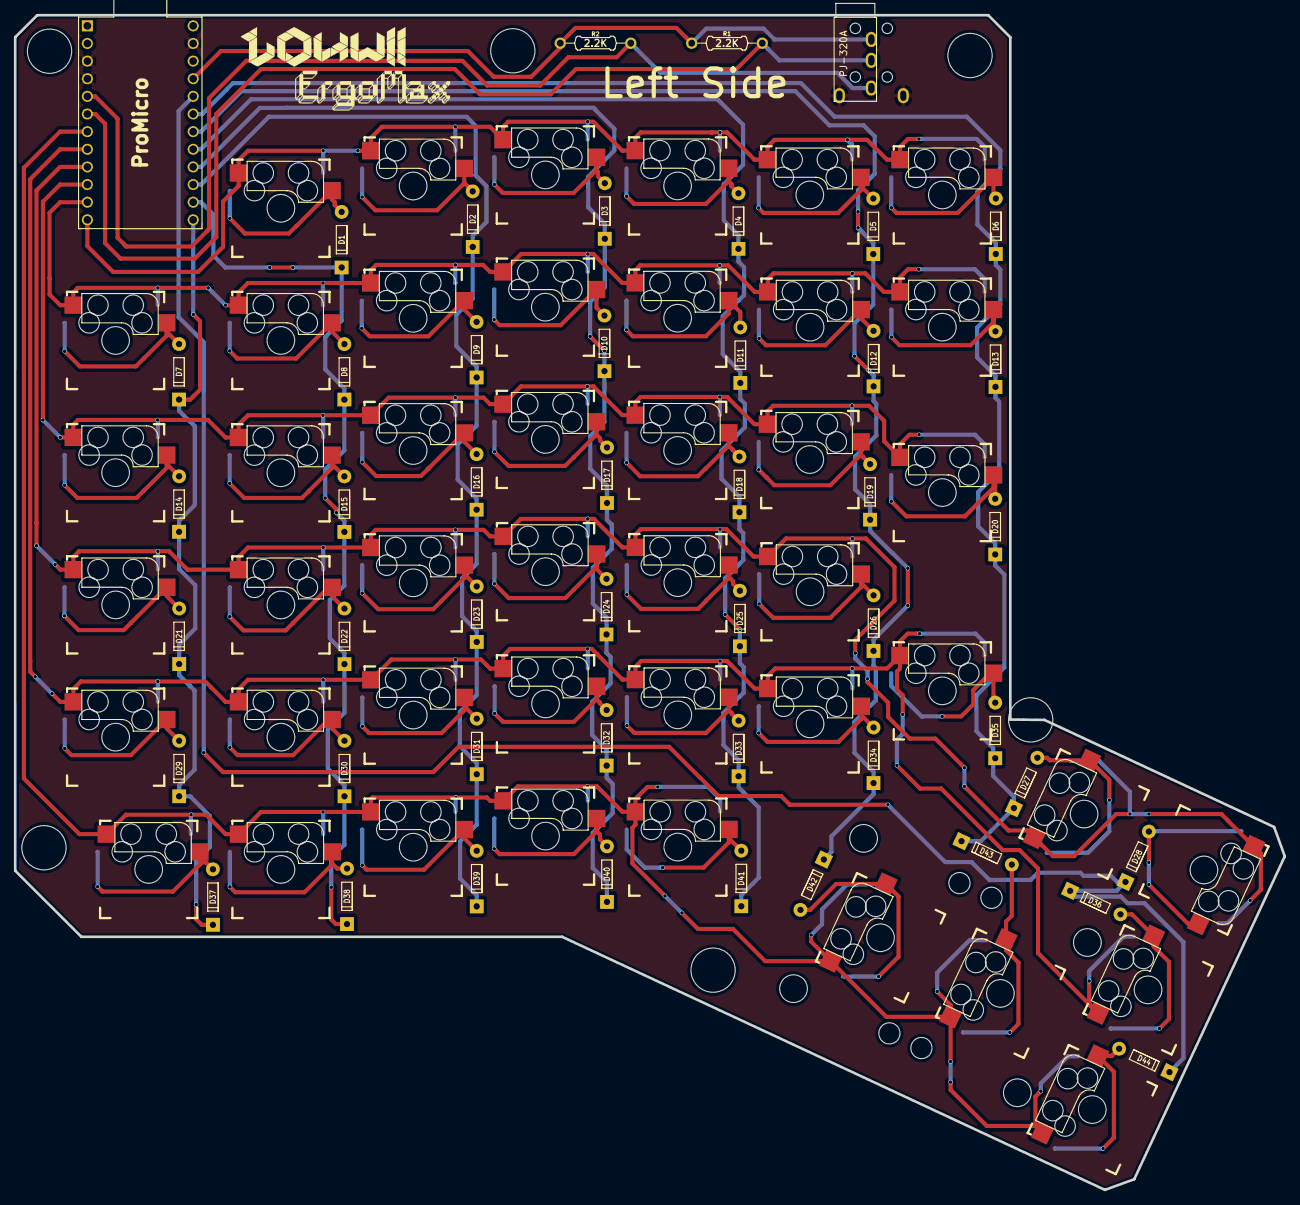
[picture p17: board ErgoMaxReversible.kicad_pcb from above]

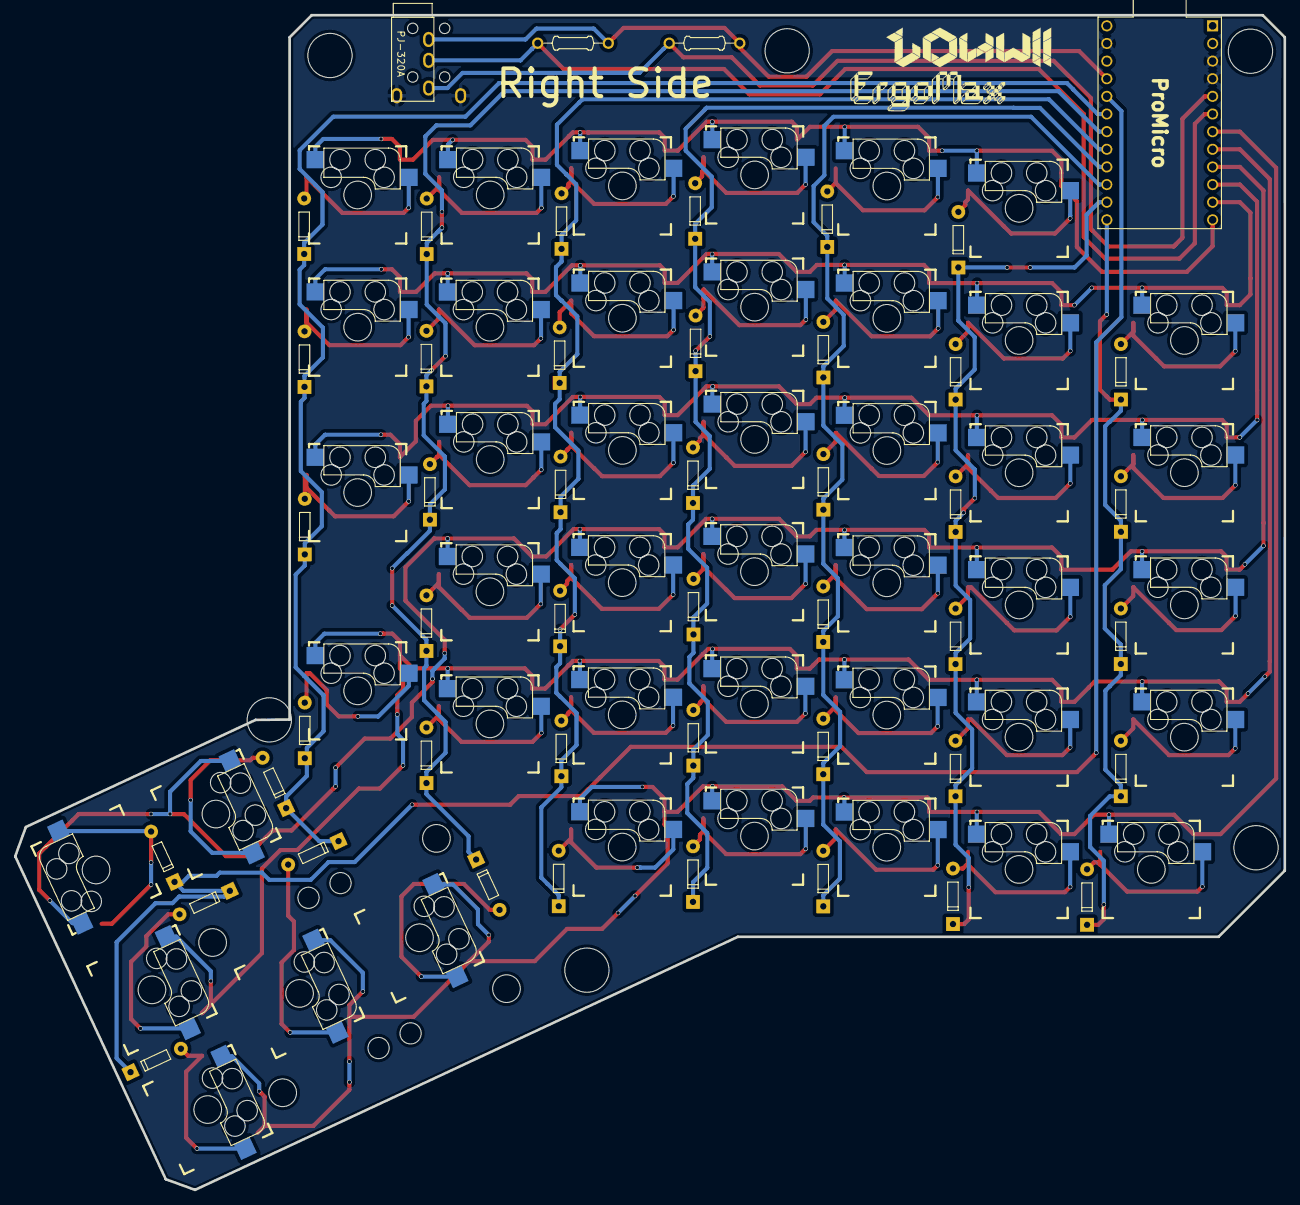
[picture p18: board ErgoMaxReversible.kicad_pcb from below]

Board: 2 copper layers, 182.8 x 169.2 mm, 106 parts (2 on the bottom side), 62 nets.

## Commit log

2018-11-10 first commit, schematics done, PCB WIP
    [ErgoMaxLeft.kicad_pcb, ErgoMaxLeft.sch]
2018-11-11 WIP: placing switch sockets on PCB
    [ErgoMaxLeft.kicad_pcb]
2018-11-12 WIP align even more switch sockets, line 4
    [ErgoMaxLeft.kicad_pcb]
2018-11-12 WIP: PCB - last row set, side keys needed
    [ErgoMaxLeft.kicad_pcb]
2018-11-13 WIP PCB place 2 right side 1.5u key sockets
    [ErgoMaxLeft.kicad_pcb]
2018-11-13 WIP PCB - place left 1.5u switch sockets
    [ErgoMaxLeft.kicad_pcb]
2018-11-13 WIP PCB: fix spacing for the 2 1.5u keys on right side
    [ErgoMaxLeft.kicad_pcb]
2018-11-13 WIP PCB: place thumb switch sockets
    [ErgoMaxLeft.kicad_pcb]
2018-11-13 WIP PCB - rotate thumb 2u keys to be oriented properly for stabs
    [ErgoMaxLeft.kicad_pcb]
2018-11-14 WIP PCB - add 2 cutouts
    [ErgoMaxLeft.kicad_pcb]
2018-11-14 WIP PCB - make rough cutout so Kicad doesn't complain anymore, add 2 mounting holes
    [ErgoMaxLeft.kicad_pcb]
2018-11-14 WIP PCB - fix placement of thumb switch sockets
    [ErgoMaxLeft.kicad_pcb]
2018-11-14 WIP PCB - add more mouting holes based on ErgoDox
    [ErgoMaxLeft.kicad_pcb]
2018-11-14 WIP PCB - make proper cutout for the top
    [ErgoMaxLeft.kicad_pcb]
2018-11-14 WIP PCB - add 2 zones and start routing
    [ErgoMaxLeft.kicad_pcb]
2018-11-14 WIP PCB - more routing
    [ErgoMaxLeft.kicad_pcb]
2018-11-15 WIP PCB - update diodes footprints to something more accurate, displayed in the proper direction
    [ErgoMaxLeft.kicad_pcb, ErgoMaxLeft.sch]
2018-11-15 WIP PCB - replace jack connector in schematics and PCB to something that actually works properly
    [ErgoMaxLeft.sch]
2018-11-15 Add stuff in README
    [ErgoMaxLeft.kicad_pcb]
2018-11-16 Change Jack 3.5 connector to PJ-320A model 4 pins
    [ErgoMaxLeft.kicad_pcb, ErgoMaxLeft.sch]
2018-11-16 create most of the routes for switches - rough, needs refining
    [ErgoMaxLeft.kicad_pcb]
2018-11-17 Re-work pro mini pinout for better wiring on PCB and finish PCB wiring
    [ErgoMaxLeft.kicad_pcb, ErgoMaxLeft.sch]
2018-11-17 add bridges so copper layers fill up most of the PCB
    [ErgoMaxLeft.kicad_pcb]
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2018-11-17 fix misaligned PCB cut limit, add gerbers files
    [ErgoMaxLeft-B.Cu.gbr, ErgoMaxLeft-B.Mask.gbr, ErgoMaxLeft-B.SilkS.gbr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]
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2018-11-17 change small resistor placement on PCB and update gerber files
    [ErgoMaxLeft-B.Cu.gbr, ErgoMaxLeft-B.Mask.gbr, ErgoMaxLeft-B.SilkS.gbr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]
2018-11-17 rename ErgoMax left ro right as it's... for the right hand
    [ErgoMaxLeft.drl, ErgoMaxRight-B.Cu.gbr, ErgoMaxRight-B.Mask.gbr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]
2018-11-17 add a 2u stab for thumb key - WIP
    [ErgoMaxRight.kicad_pcb]
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2018-11-18 modify library for MX Kailh sockets; add mounting holes in schema for PCB
    [ErgoMaxRight.kicad_pcb, ErgoMaxRight.sch]
2018-11-19 add missing stabs in schema, add them back in PCB
    [ErgoMaxRight.kicad_pcb, ErgoMaxRight.sch]
2018-11-19 replace some labels on PCB for clarity
    [ErgoMaxRight.kicad_pcb]
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2018-11-19 add custom logos in schema and PCB (added them in libs)
    [ErgoMaxRight.kicad_pcb, ErgoMaxRight.sch]
2018-11-19 add ErgoMax left part; PCB started with switches, holes, logos, stabs placed
    [ErgoMaxLeft.kicad_pcb, ErgoMaxLeft.sch]
2018-11-19 move last components to other side of the PCB
    [ErgoMaxLeft.kicad_pcb]
2018-11-20 move diodes to other side of switches; add rough wiring for rows
    [ErgoMaxLeft.kicad_pcb]
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2018-11-20 add more wiring - wiring columns is going to cause some problems
    [ErgoMaxLeft.kicad_pcb]
2018-11-21 Clean up some wiring and move jack connector to the right side!
    [ErgoMaxRight.kicad_pcb]
2018-11-21 add a reversible version with hot swap sockets - PCB WIP
    [ErgoMaxReversible.kicad_pcb, ErgoMaxReversible.sch]
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2018-11-22 add a cleaned MX switch 3d model and use it in one spot in the PCB
    [ErgoMaxRight.kicad_pcb]
2018-11-22 update switch 3d model name in PCB (was using the old name)
    [ErgoMaxRight.kicad_pcb]
2018-11-23 add stablizer model and use it on right PCB
    [ErgoMaxRight.kicad_pcb]
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2018-11-23 make diodes appear on PCB 3d model for right pcb
    [ErgoMaxRight.kicad_pcb]
2018-11-23 add pro micro 3d model and use it on right PCB
    [ErgoMaxRight.kicad_pcb]
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2018-11-24 update jack connector to be reversible; add logos on back of the pcb - reversible pcb
    [ErgoMaxReversible.kicad_pcb, ErgoMaxReversible.sch]
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2018-11-25 add readme and screenshots for the left pcb
    [ErgoMaxLeft.kicad_pcb]
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2018-11-26 add footprints for reversible diode with and without 3d model and use it on reversible pcb
    [ErgoMaxReversible.kicad_pcb, ErgoMaxReversible.sch]
2018-11-26 improve footprints on reversible PCB and add sides markings
    [ErgoMaxReversible.kicad_pcb, ErgoMaxReversible.sch]
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2018-11-27 add add values for main keys on PCB
    [ErgoMaxLeft-B.Cu.gbr, ErgoMaxLeft-B.Mask.gbr, ErgoMaxLeft-B.SilkS.gbr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]
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2018-12-01 move logos to front side of left and right PCB, add left/right writings
    [ErgoMaxLeft.kicad_pcb, ErgoMaxLeft.sch, ErgoMaxRight.kicad_pcb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]
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2019-01-23 add CAD models for the left case - WIP
    [ErgoMax-Left-Case.dxf, ErgoMax-Left.dwg]
2019-01-23 add proper export file for ErgoMax left case
    [ErgoMax-Left-Case.dxf, ErgoMax-Left.stl]
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2019-02-15 update CAD for cnc case for Ergomax left side
    [ErgoMax-Left.dwg]
2019-02-15 update eeschema with infos and add PDF file for quick view of the schematics
    [ErgoMaxLeft.sch, ErgoMaxRight.sch]
2019-02-15 update gerbers for ErgoMax right (not sure they were the last version)
    [ErgoMaxRight-B.Cu.gbr, ErgoMaxRight-B.Mask.gbr, ErgoMaxRight-B.SilkS.gbr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]
2019-02-16 change resistors side and add 3D models on ErgoMax left
    [ErgoMaxLeft-B.Cu.gbr, ErgoMaxLeft-B.Mask.gbr, ErgoMaxLeft-B.SilkS.gbr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]
2019-02-16 add jack connector 3d model to ErgoMax elft
    [ErgoMaxLeft.kicad_pcb]
2019-02-16 change resistors side on ErgoMax right and fix 3d models
    [ErgoMaxRight-B.Cu.gbr, ErgoMaxRight-B.Mask.gbr, ErgoMaxRight-B.SilkS.gbr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]
2019-02-25 add base files for acrylic case for ergo left
    [left - PCB silk.dwg]
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2019-02-26 left plate almost complete - 2 holes missing
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2019-03-02 add layer 1, add holes for logo in plate and layer 2
    [left - layer 1.dwg, left - layer 2.dwg]
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2023-02-17 Fix ground plane on reversible PCB
    [ErgoMaxReversible-B.Cu.gbr, ErgoMaxReversible-B.Mask.gbr, ErgoMaxReversible-B.SilkS.gbr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]
2023-04-19 Make reversible PCB use 5 pin hot swap footprint
    [ErgoMaxReversible-B.Cu.gbr, ErgoMaxReversible-B.Mask.gbr, ErgoMaxReversible-B.SilkS.gbr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]
2023-04-19 Fix last net connection
    [ErgoMaxReversible-B.Cu.gbr, ErgoMaxReversible-B.Mask.gbr, ErgoMaxReversible-B.SilkS.gbr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]
2023-04-20 Fix net
    [ErgoMaxReversible-B_Cu.gbr, ErgoMaxReversible-B_Mask.gbr, ErgoMaxReversible-B_Silkscreen.gbr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]
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
